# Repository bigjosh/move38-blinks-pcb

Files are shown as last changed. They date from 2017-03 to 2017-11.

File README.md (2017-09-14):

## Schematic

### Theory of Operation

### Display LEDs

These are multiplexed with a single IO pin driving the anode of each pixel and the RGB cathodes connected to timers to PWM them (blue is slightly different, see booster below). 

The software lights each pixel in turn fast  enough that they all seem to be on continously. You could potentially also light multiple pixels at the same time if they have the same color, but ultimately you will hit the maximum current rating for the IO pins so probably not worth it. You might be able to drive one or 2 pixels statically if you wanted it to look really bright, but be careful not to blow them!  

Q: Why not put all the anode drivers on a single `PORT` in sequence so we can just walk a bit rather than needing a look-up for which port/bit is next?

A: This would have been really elegant, but I really wanted to be able to drive the RGB lines with timers for efficiency, so PORTD is out. We could have used PORTB or PORTC, but I wanted to save those to support efficient bit-based processing of the IR LED since that is timing sensitive.  Since the look-up only happens a few hundred times per second, not that big a deal, right?
 
### Booster circuit

The blue LEDs sometimes need a larger forward voltage than the battery can directly supply, depending on how new the battery is and the type of blue LED.

The booster uses a modified charge pump to increase the voltage across the blue LED by driving the cathode below zero volts.

More info on the modified charge pump here...

https://wp.josh.com/2017/03/20/blinking-blue-powering-a-3-7-volt-led-from-a-2-4-volt-coin-cell-with-a-0-02-charge-pump/

Q: Why do we need the IO pin?

A: If the battery voltage is high and the blue forward voltage is low, we risk the blue LED coming on dimly from current that flows though the diode. The IO pin goes high to block this current.  

Q: Why do we need the diode? Can't we just connect the capacitor to an IO pin and only activate the pin when we are pushing charger down?

A: Because the IO pins on the AVR have clamping diodes, the second the negative voltage dropped below ~-0.2V, the clamping diode would start supplying current. The external diode blocks this.

Q: Can we use a MOSFET here tied to the input of the capacitor to save an IO pin, a BOM line, and the forward drop across the diode? 

A: No matter which way you try to put the MOSFET, you will end up with the body diode either quenching the negative voltage, or letting the quiescent current flow. You could do it with 2 back-to-back MOSFETs, which makes sense if we need that IO pin back (to, say, support the ATMEAG168 P and PA variants again since they have fewer IOs), but for now the PB variant is cheapest anyway so no need to add the extra part.

Q: Why pick the 3 pin BAT54 package rather than just a 2 pin diode?

A: Glad you asked!

1. This lets you substitute the extremely popular BAT54C with no changes (the 2nd diode is unused)
2. There is no way to install the 3 pin package backwards
3. Those little SOD-523F packages are PITA to reflow 

## Future Directions

* Add a boost for green too so we can run the battery all the way down to 1.8V. Doesn't seem necessary for now, and don't know if there is really enough energy left down there to be worth it (what if we only get like 10 mins?).
* CAPSENSE somewhere? Maybe on button body? Nice to know that a finger is approaching or a hand just waved above. Free, just design time.

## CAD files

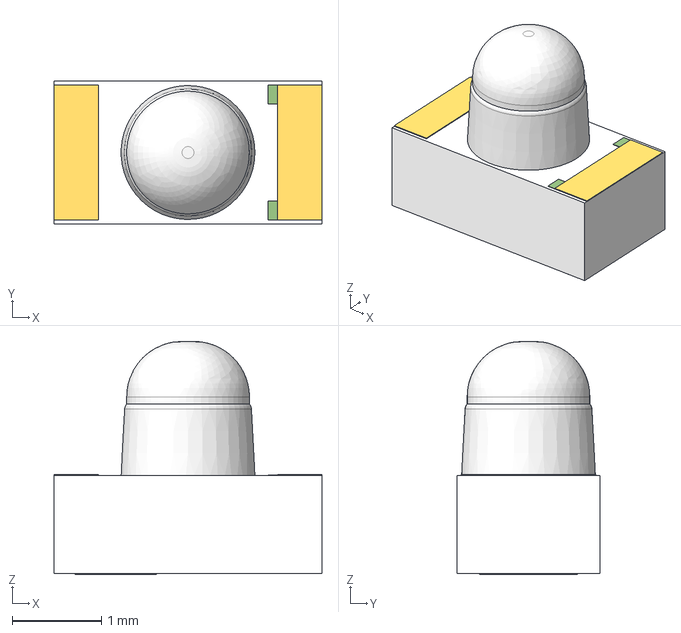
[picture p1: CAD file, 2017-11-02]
diptrace/tile/3dmodels/IR26-51C.step
3.00 x 1.60 x 2.61 mm

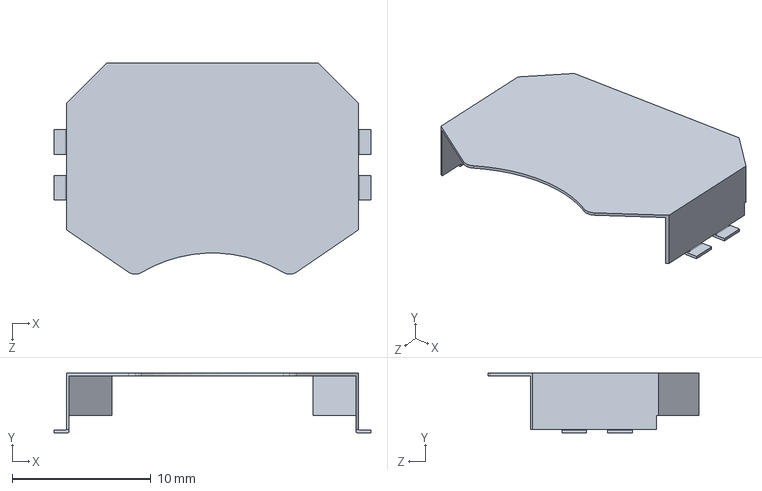
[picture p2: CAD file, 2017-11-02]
diptrace/tile/3dmodels/BK-912.STEP
22.9 x 4.32 x 15.2 mm

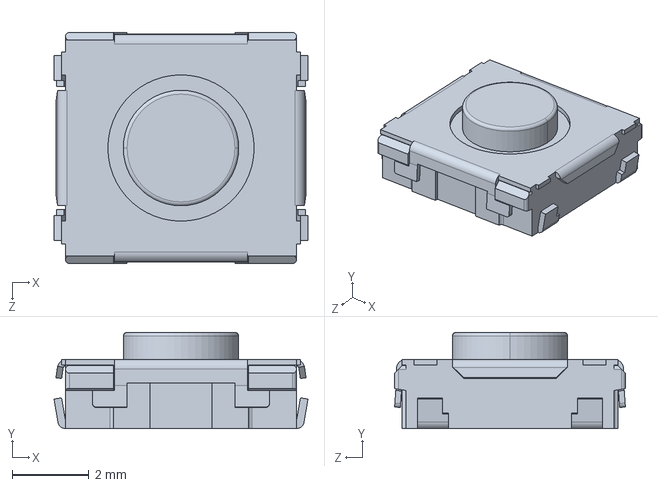
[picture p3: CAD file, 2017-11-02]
diptrace/tile/3dmodels/EVQQ2-BFKPUY-02W.STEP
6.60 x 2.50 x 6.00 mm

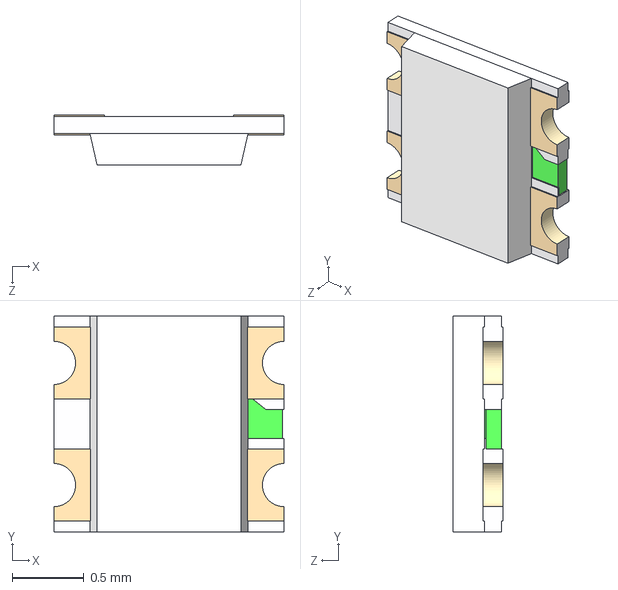
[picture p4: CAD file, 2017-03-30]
diptrace/tile/3dmodels/RGB-LED-HSMF-C114.STEP
1.60 x 1.50 x 0.35 mm

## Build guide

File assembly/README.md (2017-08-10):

### Tile Assembly Notes

## 0606 RGB LED

The green dot on the LED face always aligns with the dot on the silk. All green dots on RGB LEDs point towards outside edge of PCB.

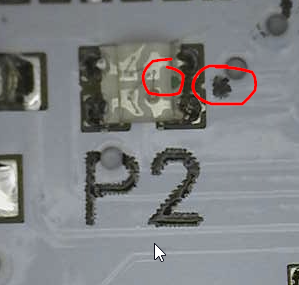
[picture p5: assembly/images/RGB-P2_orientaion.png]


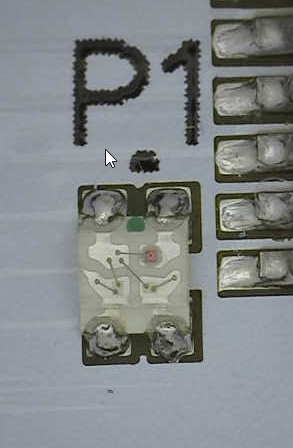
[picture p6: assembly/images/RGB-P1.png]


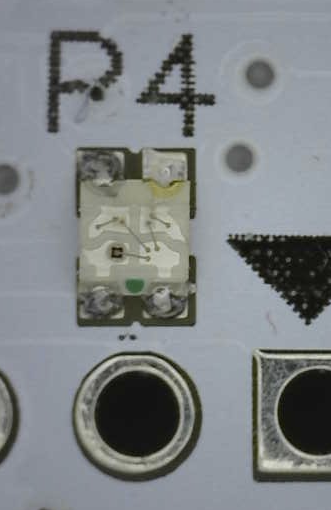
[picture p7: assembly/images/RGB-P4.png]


## IR LED

IR LEDs are side facing. They always point with lens towards PCB edge

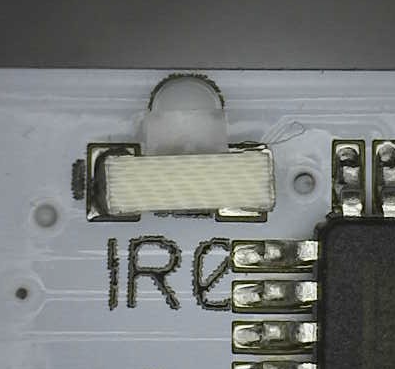
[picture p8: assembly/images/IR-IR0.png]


Each IR LED has a green stripe on the back which aligns to the line on the silk

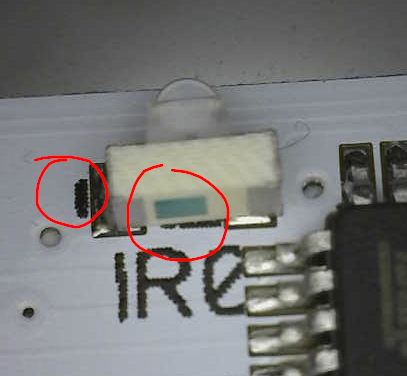
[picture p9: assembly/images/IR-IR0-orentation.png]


### Completed PCB

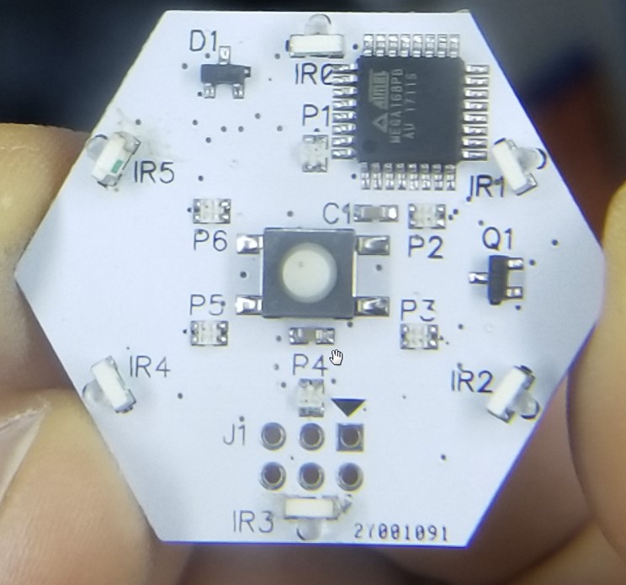
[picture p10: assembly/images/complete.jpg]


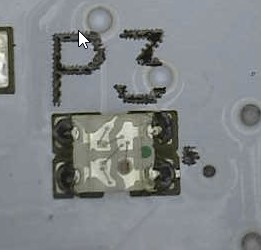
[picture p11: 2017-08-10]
assembly/images/RGB-P3.jpg

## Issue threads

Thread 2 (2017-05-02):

Add MOSFET to low side of blue charge pump

bigjosh, 2017-05-02:
More efficient than diode, and one less BOM line since we need MOSFET for reverse battery protection anyway.

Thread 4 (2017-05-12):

Add reverse battery protection

bigjosh, 2017-05-12:

bigjosh, 2017-05-12:
Added in rev3 with low-side n-chan MOSFET

Closed 2017-05-12.

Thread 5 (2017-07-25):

Add a debug port to PCB so we can snoop on PE2

bigjosh, 2017-07-25:
PE2 unused now. Exposing this And ground could give us a nice place to attach a scope or serial port for deep debugging.

Closed 2018-01-16.

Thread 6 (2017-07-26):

Make IR LED pads wider to get better meniscus and adhesion?

bigjosh, 2017-07-26:
Really tight now, and LED so seem to pop off too easily.

bigjosh, 2017-08-11:
Also add a "K" to cathode side on silk. Also replace the side bar on silk with a block to visually line up with the green block on the part. PCBWAY had a hard time with this!

Closed 2018-01-16.

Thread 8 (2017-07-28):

Fix BLUE pixel fine brightness control

bigjosh, 2017-07-28:
Had to kill this to make our timeslice deadline to not interfere with IR.

Will need to revisit this and move the blue charging to the background or a different time-slice phase?

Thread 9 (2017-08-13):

IR1 RX seems to fire sporadically in sync with IR0 real RX fire - but only when programmer attached

bigjosh, 2017-08-13:
Hmm... This is a weird one.

Checked all the IR LEDs and only IR1 affected.

Really confirmed that it is the programmer (Dragon) and not just the programming cable.

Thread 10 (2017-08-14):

Lower clock speed to 1Mhz for FCC part 15

bigjosh, 2017-08-14:
Likely requires switching to a slots-based IR system so that IR is no longer dependent on other ISRs completing fast enough.

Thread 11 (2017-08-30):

Put keepout in battery slide path to prevent shorts if resist rubs off

bigjosh, 2017-08-30:
Looks like after many insertions, the resist is rubbing off the traces and the batter could potentially touch one on the way in and cause havoc.

bigjosh, 2017-09-01:
Might want to clear out ALL traces under the battery. I think I have a unit now that I can squeeze and make the battery touch a via.

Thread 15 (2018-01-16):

Dev Candy PCB: Transistor Q1 footprints are reversed!

bigjosh, 2018-01-16:
Drain should be connected to ground, not source!

Workaround is to install Q1 on its back.

bigjosh, 2018-02-15:
Fixed in 41ecb8b8d236f80c75bf7b54d6305ae973181d8a

Closed 2018-02-15.

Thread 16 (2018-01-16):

Dev Candy PCB: Service port connector J2 pads are reversed.

bigjosh, 2018-01-16:
Workaround is to install the connector rotated 180 degrees> result is functional but part does not line up with the silk outline so ugly.

bigjosh, 2018-02-15:
Fixed in 41ecb8b8d236f80c75bf7b54d6305ae973181d8a

Closed 2018-02-15.

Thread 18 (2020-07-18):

R pads on Serial board should be 0603

bigjosh, 2020-07-18:
Wrong footprint

Closed 2020-07-20.

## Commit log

2017-03-27 Pin down (pun) the RGB pin assignments
2017-03-30 Added 3d models. Thickened power traces.
    [RGB-LED-HSMF-C114.STEP, ir emmitter.step]
2017-04-02 Refine IR LED 3d model
    [ir emmitter.step]
2017-04-10 Blue boost and optional green boost. Beefed up power traces - maybe loose decoupling cap?
2017-04-28 Added new component for ATMEGA168PB variant (has different power pins than P or PA)
2017-04-28 Replaced ATMEAG168PA with proprt PB variant, connected GND to proprt power pin for new part
    The PA has lots of GND pins, but on the PB one of them becomes an IO.
    Bad luck had GND connected here- which worked becuase of internal
    clamping diode but with reduced current.
2017-04-29 Temp rework to be able to turn off blue LED when battery voltage is too high
    Uses a ATMEGA168PB only pin, so will not work with PA or P part.
    Utimately might want a dual mostfet here.
2017-04-30 Cleaned up schematic to match reworked units. Repinned BAT54C so swappable with BAT54. Added README.
    Laid out, but never going to be produced becuase want to try to use a
    dual MOSFET for battery protection and charge pump
2017-05-02 Added new LED component for differtent ones from China, updated ATMEGA component to match part
2017-05-02 Timer-based fades working for red & green! Yeay!
2017-05-02 Switched to Timers, not working - all colors too dim
2017-05-02 All three colors working on Timers!
    Blue too bright, need to balance colors
2017-05-03 Simple color demo working nicely, on to button and power..
2017-05-12 Added CZ3 variant to test the 6 pin RGB LEDs.
2017-05-12 Reverse battery protection off todo list in readme!
2017-05-13 Added ECB LED variant
2017-05-13 Added LED variant CZ2
2017-07-13 Switch back to standard 6 pin ISP
2017-07-14 Updated battery clip to only connect one side. Ripped up traces waiting for TopoL.
2017-07-14 Rename refdes for IR LEDs to IR0-IR5
    Should have done this long ago.
2017-07-14 Clean up schematic power trace width, IR 3d model
2017-07-14 ISR timing completely determinitically locked in with no slop. SO DAMN SWEET!
    Turn of pin change mask before charging, back on right before we finsh. Exactly one trigger per bit. Always. Every time. I love hardware!!!
2017-07-14 Sweetened up the IR coms ISR with PIN bit toggling. Saves 10 bytes, and so elegant.
2017-07-14 IR background recharge implemented. Perfect. <100us of jitter on pulse detect.
2017-07-15 Updated PCB. Complete but only Ok layout.
2017-07-23 Switching over to fixed slices rather than stopwatch for pulse RX
2017-07-25 TX working. Sends a running count 0-255 with odd parity on top IR LED at 1Hz.
2017-07-28 Timeslice phases working, but blue pixel charge talking to long (>200us).
2017-07-28 More work on slots
2017-07-29 Refined slot decode. Not tested.
2017-08-10 Added assembly info
2017-08-10 Add RGB LEDs to assembly readme
2017-08-10 Added assembly photos
2017-08-10 change assembly folder case
2017-08-12 Timer1 added to IR comms. TX working on timer ISR and sending test data on all faces.
2017-08-27 Add mounting hole, increase IR pad sizes, all LEDs on correct radials
2017-08-27 Updated IRLED 3dmodel to show green orentation dot
    [IR26-51C.step, ir emmitter.step]
2017-08-27 Added 3d models for battery holder and button
    [BK-912.STEP, EVQQ2-BFKPUY-02W.STEP]
2017-08-27 Make K mark on IR LEDs smalelr to avoid silk inerference on U1
2017-09-13 Refine to ready design for ordering proof pcbs
    Cleaned up traces and silks
2017-09-13 Remove firmware to Arduino-platform repo
2017-09-13 Re-opg folders to move firmware out of repo
    [BK-912.STEP, EVQQ2-BFKPUY-02W.STEP, IR26-51C.step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]
2017-09-13 Clean up old assembly folder
2017-10-15 Mounting hole connected to power net
    Genrates DRC errors and I can not figure out why, so just ignoring for
    now. Will ask tech support.
    http://www.diptrace.com/forum/posting.php?mode=post&f=5&sid=8417bee4cfba6fee3716825b6ec7cfae
2017-10-17 Mounting hole routed
2017-10-19 Added connector to sch
2017-10-19 Rename pixels on PCB
2017-10-19 Added new ATMEGA component with better visual pin placement
2017-10-19 PCB laid out, pixels renumbered. ready to route
2017-10-21 Potyential good route, but awkward traces
2017-10-21 Pretty fricken nice route - with AUX pin even!
2017-10-21 Cut some corners
2017-10-21 Shrink silk triangle on ISP
    Was ovberlapping new mounting screw anulus
2017-10-21 stash- visually clean up schematic
2017-10-24 Signal Layer Logo with 3mm unit size pattern created and added.
2017-10-24 Refine components to match BOM, add PLACE field
2017-10-24 BOM updates cascaded all the way to PCB layout
2017-10-24 Revert to logo with snug mask outline
    This is how we will produce assembled boards unless something changes.
